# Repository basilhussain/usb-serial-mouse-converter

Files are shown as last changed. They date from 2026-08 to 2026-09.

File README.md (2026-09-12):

# USB-to-Serial Mouse Converter

This is an adapter to convert a USB mouse to work with an RS-232 serial interface. Gives the capability to use a modern USB optical mouse with vintage PC computer hardware, where original serial ball mice are frequently scarce, unreliable, or just unpleasant to use.

Designed to be mounted with a bracket internally in a regular PC expansion card chassis slot.

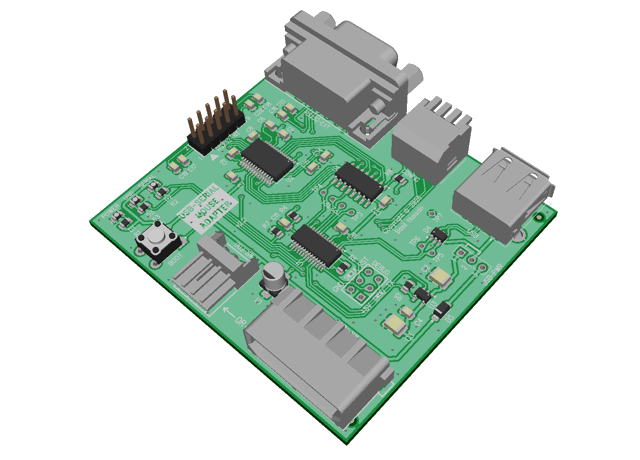
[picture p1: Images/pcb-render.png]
Rendered image of PCB

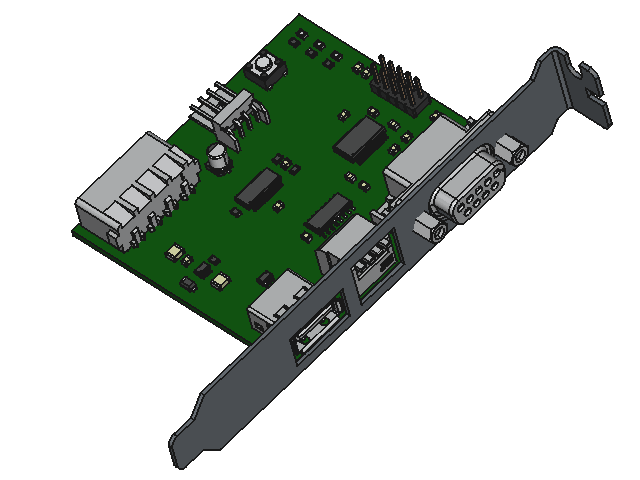
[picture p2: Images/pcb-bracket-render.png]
Rendered image of PCB with mounting bracket


## Features

* Emulates four different serial mouse types:
  * Microsoft 2-button
  * Mouse Systems 3-button
  * Logitech 3-button
  * Microsoft 3-button wheel
* Supports virtually any USB HID pointing device – mouse, trackball, touchpad – including scroll wheel, wireless, combo, and hi-DPI devices.
* Connects to host system's RS-232 serial port via either:
  * External female DE-9 connector
  * Internal male 10-pin header
* Powered by regular PC power supply connector, either larger Molex HDD-type or smaller Berg FDD-type.
* Custom bracket design for mounting in standard PC expansion card chassis slot.
* Configuration adjustable via externally-accessible DIP switches.
* USB port short-circuit and over-current protected (500 mA capable).
* Supports optional Plug-and-Play ID for auto-detection by capable operating systems (e.g. Win9x) and drivers.
* Supports subset of proprietary Logitech serial probe/identification commands for auto-detection by Logitech drivers.
* Firmware upgradable over USB.

## Installation & Setup

1. Screw the adapter board's bracket into a free chassis expansion slot.
2. Plug a spare power supply cable into **either** the larger Molex HDD-type **or** smaller Berg FDD-type power connectors. **Do not use both power connectors.**
3. Connect **either** external **or** internal serial cables, as described below.
4. Configure DIP switches according to desired usage (see *Configuration* section).

> [!NOTE]
> The adapter board does not plug into the motherboard expansion bus, so if you have a free chassis slot that doesn't have a corresponding motherboard connection, use that to avoid taking up space that could otherwise be used for a card!

### External Serial Cable

**You will require a male-to-female 9-pin DE-9 RS-232 serial cable.**

1. Connect one end of the cable to the 9-pin port on the adapter.
2. Connect the other end of the cable to a free 9-pin serial port on the host machine. Effectively, you're looping the serial cable from the machine back to itself.
3. Set port selection DIP switch to 'External' (see *Configuration* section below).

### Internal Serial Cable

**You will require a 10-pin ribbon cable with 5x2 dual-row 2.54mm (0.1") pitch female IDC connectors.**

The internal serial connection is designed to connect to an internal pin header on the motherboard or a serial expansion card of the host machine.

> [!IMPORTANT]
> The internal 10-pin header uses the 'Intel' pin-out; it is not compatible with the other common 'AT'/'Everex' pin-out.

1. Connect one end of the cable to the adapter's pin header labelled `RS232-INT`. Note the arrow indicating pin 1, which should align with the red stripe on the cable.
2. Connect the other end of the cable to the host machine's internal RS232 port header. Again, ensure the red stripe is aligned to pin 1. Be aware that pin 1 markings on motherboards and expansion cards may vary, so if not immediately apparent, inspect closely.
3. Set port selection DIP switch to 'Internal' (see *Configuration* section below).

If in doubt about host machine's serial header location, orientation, or exact pin-out, refer to your motherboard or serial expansion card's documentation.

> [!NOTE]
> You may need to alter jumpers, DIP switches, or BIOS settings to enable and configure (port address, IRQ, etc.) an internal serial port header.

### Configuration

Serial mouse emulation type, Plug-and-Play ID, and external/internal serial port selection are configured via DIP switches.

> [!IMPORTANT]
> If you change any of the switches (except the port selection switch) while the system is running, you will need to either unload and re-load the mouse driver or restart the system for changes to take effect.

Numeric column headings in the tables below correspond to the labels on the DIP switch, and the off/on values in each row are what each individual switch should be set to.

#### Serial Mouse Type

Selects what type of serial mouse to emulate.

| Serial Mouse Type | 1 | 2 |
| --- |:---:|:---:|
| Microsoft 2-button | OFF | OFF |
| Mouse Systems 3-button | ON  | OFF |
| Logitech 3-button | OFF | ON  |
| Microsoft 3-button Wheel | ON  | ON  |

Logitech emulation includes support for Logitech-proprietary probing/identification commands sent to the serial mouse, but not any others such as baud rate, protocol, or report rate switching. Logitech command support is disabled when PnP is enabled.

Microsoft Wheel support depends on both driver and application support; otherwise, wheel will be limited to acting as middle button.

#### Plug and Play ID

Whether to emit Plug and Play ('PnP') data when the host driver or operating system resets/probes the mouse (by toggling the serial RTS line), so that the mouse can be automatically identified.

| PnP ID | 3 |
| --- |:---:|
| Disabled | OFF |
| Enabled  | ON  |

Enable this switch when using Windows 9x (or any other O/S that supports PnP). Disable when using DOS or Windows 3.x.

This switch has no effect in Microsoft 2-button and Mouse Systems mode (i.e. always acts as if disabled) – these mice pre-date PnP, so there is no identifier for them.

#### RS-232 Port Select

Selects between the internal or external RS-232 serial ports.

| RS-232 Port | 4 |
| --- |:---:|
| Internal | OFF |
| External | ON  |

Unlike the other switches, **this switch is 'live'** – i.e. takes effect immediately.

### Other Operational Notes

There are three on-board LEDs:

* 🟢 **Power** (green) – Should illuminate whenever the board is receiving 5V power from the Molex connector.
* 🔴 **USB status and activity** (red) – Will illuminate when a USB mouse is connected and has been successfully enumerated. Will flash when USB activity is occurring. Activity should be fairly constant regardless of movement or clicking due to the regular USB polling traffic.
* 🔴 **Serial status and activity** (red) – Will illuminate when the serial RTS signal has been asserted; i.e. when a driver has enabled and probed the serial mouse. Will flash when serial data is being sent. Activity will generally only be indicated when the mouse is moved, clicked, or scrolled.

**Connecting USB devices through a USB hub is not supported.** The USB device must be directly connected to the adapter.

The USB port is over-current and short-circuit protected. Maximum allowed current draw is approximately 500mA. Should the current limit be exceeded, the USB power will be shut off and the USB status LED will go out. To recover from this state, the board must be power-cycled.

The 3-way jumper labelled `USB-PWR` is only used for facilitating firmware upgrades via the USB port and should not normally need adjustment. **It must always be in the 1-2 position during normal operation.** The other position (2-3) allows for powering the board via the USB port during firmware updates.

## Hardware

For schematic, PCB layout, and Bill of Materials (BOM), see the `Hardware` sub-folder.

Gerber files for PCB manufacturing and 3D STEP file for sheet-metal mounting bracket can all be found in the 'Releases' section of the GitHub repository.

## Firmware

For firmware source files, firmware update procedure, and build procedure, see the `Firmware` sub-folder.

You can find the latest compiled firmware in the 'Releases' section of the GitHub repository.

## Motivation

There are many existing open-source projects to adapt USB mice to a serial interface, so why yet another?

A lot of other projects are somewhat limited, flawed, or buggy. Many don't properly support all varieties of USB mice, have limited serial mouse emulation, or make mistakes or omissions in their handling of certain features. Most also do unnecessary work due to lack of understanding of the USB specification.

I decided to create this project to address many of these shortcomings.

Below I'll discuss a little on some of the more notable things I discovered while researching existing solutions.

### Simplified Boot vs. Native Report Modes

One particular flaw common to all projects found based on the Raspberry Pi Pico microcontrollers is caused by their use of the ubiquitous [Tinyusb](https://github.com/hathach/tinyusb/) library.

Out of the box, the Tinyusb library only works with USB HID mice that support 'Boot' mode. In the HID standard, Boot mode is a simplified, limited-capability mode intended for BIOSes and other system bootloaders, so that they don't have to implement the entire, complex HID specification. In Boot mode mouse reports follow a standardised, fixed report format that is limited to low resolution (8-bit) axis values and only 3 buttons.

However, some mice either do not support Boot mode at all, or when told to use Boot mode wrongly continue to report their native higher-resolution (e.g. 12- or 16-bit) data in an incompatible format.

Boot mode also does not cater to more complex devices (e.g. a combo device such as keyboard with integrated trackpad) that use Report IDs to differentiate between reports sent for each sub-function.

All this leads to Tinyusb-based projects often having limited USB device compatibility; they tend not to work with 'fancier' devices like high-DPI mice or combo devices.

### "Hey, Not So Fast!"

Another common flaw comes from an apparent lack of detailed understanding of the USB specification, particularly when combined with use of a library that abstracts away some of the details of USB devices.

When a USB device is first connected, the enumeration process involves the device sending some 'descriptor' data to the host. This descriptor data describes what class of device it is, its capabilities, etc. One part of this data that is supplied by devices such as mice and keyboards is the `bInterval` field of an Endpoint descriptor. This tells the host system how often (in milliseconds) the USB device would like to be polled for data. For example, a mouse might give a `bInterval` of 10ms; that is, it can provide updates 100 times per second.

However, when it comes to serial mice, their update rate is limited by the rate at which they can spit data across the slow serial connection. Typical serial baud rate is only 1200 baud, which if you do the math works out to (depending on protocol) between 24 to 44 possible updates per second.

This disparity between update rates causes many projects to implement some kind of aggregation scheme, where they will collect multiple more-frequent USB reports and sum the pointer movement between serial updates.

But what if I told you that is wholly unnecessary? You see, that `bInterval` value mentioned earlier is a *minimum* interval time; it's the *fastest* rate at which the USB device should be polled. There's actually nothing stopping you from polling a USB mouse at a *slower* rate! So you can simply match your USB polling rate to the fastest rate at which you can send serial updates, and the mouse just does all the aggregation for you!

### Identity Problems

Some projects do not properly implement the process of the emulated serial mouse identifying itself to the host system when the host toggles the RTS line of the serial port.

In one, when working in basic 2-button Microsoft mode, the ident value incorrectly claims to be a 3-button mouse. Another identifies as a 3-button mouse, but in update reports never actually sends the 4th protocol byte containing the state of the middle button. Lastly, another tries to identify with additional Plug-and-Play ID data, but unfortunately the data it supplies is malformed.

## Resources

Here are some links to helpful technical resources concerning USB, HID, serial mouse protocols, and more, as well as a selection of other open-source projects.

### References

* [*Universal Serial Bus Specification, Revision 2.0*](https://www.usb.org/document-library/usb-20-specification) - USB Implementers Forum
* [*USB Device Class Definition for Human Interface Devices (HID), Version 1.1*](https://www.usb.org/document-library/device-class-definition-hid-111) - USB Implementers Forum
* [*HID Usage Tables for Universal Serial Bus (USB), Version 1.7*](https://usb.org/document-library/hid-usage-tables-17) - USB Implementers Forum
* [*USB in a NutShell*](https://www.beyondlogic.org/usbnutshell/usb1.shtml) - Beyond Logic
* [*Plug and Play External COM Device Specification, Rev. 1.00*](https://ftpmirror.your.org/pub/misc/ftp.microsoft.com/developr/drg/Plug-and-Play/Pnpspecs/) - Microsoft Corporation
* [*Hardware Design Guide for Microsoft Windows 95*](https://archive.org/details/bitsavers_microsoftwignGuideforWindows951994_24657772) - Microsoft Press
* [*LogiMouse C7 Technical Reference Manual*](https://archive.org/details/bitsavers_logitechLormwareRev3.0Jan86_1143953) - Logitech Inc.
* *3D Mouse & Head Tracker Technical Reference Manual* - Logitech Inc.
* [*CyberMan 3D SWIFT Supplement, Version 1.0*](https://archive.org/details/bitsavers_logitechcyFTSupplementVer1.0upd199401_3268361) - Logitech Inc.
* [*Differences between the Logitech Mouseman and C7/C9 Serial Mouse?*](https://www.scosales.com/ta/kb/104043.html) - SCO Unix Support Knowledge Base
* *M-1 Mouse Technical Reference Manual* - Mouse Systems Corporation
* [*M-2 Optical Mouse Technical Reference Manual*](https://archive.org/details/bitsavers_mouseSysteicalMouseTechnicalReferenceJan1984_519574) - Mouse Systems Corporation
* [*Optical Mouse Technical Reference Manual, Models M2 and M3*](https://archive.org/details/bitsavers_mouseSystetemsOpticalMouseTechnicalReferenceModels_351372) - Mouse Systems Corporation
* *HT82M13, HT82M33A, HT6513 Datasheets* - Holtek
* *EM83701, EM84520 Datasheets* - EMC
* [*The RS-232 Solution*](https://archive.org/details/The_RS-232_Solution_by_Joe_Campbell) - Joe Campbell, Sybex Computer Books
* [*Design Notes: Interface Circuits for TIA/EIA-232-F (SLLA037A)*](https://www.ti.com/lit/an/slla037a/slla037a.pdf) - Texas Instruments
* [*Serial Mouse Info, Release 05*](https://web.archive.org/web/19991116104658/http://www.softnco.demon.co.uk/SerialMouse.txt) - Chris Softley
* [*PC Mouse Information*](https://www.epanorama.net/documents/pc/mouse.html) - Tomi Engdahl
* [*Protocol Documentation*](https://github.com/davidebreso/ctmouse/blob/main/doc/protocol.txt) - CuteMouse Driver

Apologies that links to all items cannot be provided, as some were acquired from non-linkable or non-public resources, or from sources that have been forgotten. 😅

### Other Projects

* https://github.com/Yftul/usb-mouse-2-isa
* https://github.com/Aviancer/amouse/
* https://github.com/LimeProgramming/USB-serial-mouse-adapter
* https://github.com/polpo/picogus/
* https://github.com/rasteri/HIDman
* https://github.com/mborjesson/USB-Mouse-to-Serial
* https://github.com/6502addict/usb-to-serial-mouse
* https://github.com/Lameguy64/LameMouseConverter
* https://github.com/matze79/PS2-Adapter
* https://github.com/mniemela/PS2toSerial
* https://github.com/Quwy/PS2-Serial-Mouse
* https://github.com/trol73/avr-mouse-ps2-to-serial
* https://github.com/necroware/ps2-serial-mouse-adapter/
* https://github.com/danbrakeley/PS2toCDi

## Licence

Copyright © 2026 Basil Hussain.

Firmware is licenced under the [GNU General Public License 3.0](https://www.gnu.org/licenses/gpl-3.0.html); see accompanying LICENCE.txt for details. Uses [Nanoprintf](https://github.com/charlesnicholson/nanoprintf) by Charles Nicholson, licenced under the terms of [Unlicense](http://unlicense.org).

Hardware schematic and PCB design is licenced under the [Creative Commons Attribution-NonCommercial-ShareAlike 4.0 International](https://creativecommons.org/licenses/by-nc-sa/4.0/) licence.

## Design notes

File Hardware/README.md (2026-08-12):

This folder contains the design files for PCB schematic and layout, as well as 3D model for mounting bracket.

Gerber files for PCB manufacturing and 3D STEP file for sheet-metal mounting bracket can all be found in the 'Releases' section of the GitHub repository.

Schematic and PCB layout were created with [DipTrace](https://diptrace.com) version 5.x.

Mounting bracket 3D model was created in [FreeCAD](https://www.freecad.org) version 1.x.

## Bill of Materials

| Reference Designator | Type | Value | Package | Specification | Manufacturer | Manufacturer Part Number | Alternative Parts (Mfr. & P/N) | Quantity | LCSC Part Number |
| --- | --- | ----- | --- | --- | --- | --- | --- | --- | --- |
| C1 | Electrolytic Capacitor | 10µF  | | ≥16V, ±20%, ≥2000h @ ≥85°C, 4mm diameter, ≤6mm height | (Any) | | | 1 | C249565 |
| C2, C3 | Ceramic Capacitor | 10µF  | 1210 | ≥50V, ±10%, X5R/X7S/X7R | (Any) | | | 2 | C2918502 |
| C4, C5, C6, C7, C8, C9, C10, C11, C12 | Ceramic Capacitor | 100nF | 0805 | ≥25V, ±10%, X7R | (Any) | | | 9 | C1711 |
| C13, C14, C15, C16 | Ceramic Capacitor | 4.7nF | 0805 | ≥25V, ±10%, X7R | (Any) | | | 4 | C1744 |
| D1 | LED | | 0805 | Yellow-Green, ~572 nm, 25-75 mcd @ 5mA IF | (Any) | | | 1 | C965816 |
| D2, D3 | LED | | 0805 | Red, ~620 nm, 25-75 mcd @ 5mA IF | (Any) | | | 2 | C965812 |
| D4 | TVS Diode | | SOT23-6 | | ST Microelectronics | USBLC6-2SC6 | | 1 | C5180249 |
| D5 | Schottky Diode | | SOD-123FL | ≥20V, ≥200mA, ≥400mW | (Any) | 1N5819W | 1N5817W; BAT43W; BAT42W | 1 | C963381 |
| J1 ‡ | Connector | | | Berg/FDD, 4-pin, 2.5mm pitch, horizontal, through-hole | TE | 171826-4 | XKB X2511WR-04A; CJT A2544WR-4P; Hongxing HX25025-4WA | 1 | C590635 |
| J2 ‡ | Connector | | | Molex/HDD, 4-pin, 5.08mm pitch, horizontal, through-hole | TE | 641737-1 | XFCN M5082RK-04P | 1 | C492552 |
| J3 | Connector | | | DE-9, female, horizontal | TE | 2311765-1 | XUNPU D-SUB-DR-9PCM-CB | 1 | C19077337 |
| J4 | Pin Header | | | 2.54mm pitch, 2x5, vertical | (Any) | | | 1 | C42385496 |
| J5 | Connector | | | USB type-A, female, horizontal, through-hole | TE | 292303-6 | SHOU HAN AF 90 WJDG | 1 | C456018 |
| J6 | Pin Header | | | 2.54mm pitch, 1x5, vertical | (Any) | | | 1 | |
| J7 | Pin Header | | | 2.54mm pitch, 1x3, vertical | (Any) | | | 1 | |
| R1, R2, R3 | Resistor | 1kΩ | 0805 | ±5%, 125mW, 150V | (Any) | | | 3 | C25623 |
| R4, R5, R6, R7, R8 | Resistor | 4.7kΩ | 0805 | ±5%, 125mW, 150V | (Any) | | | 5 | C26022 |
| S1 | DIP Switch | | | 4 switches, SPST, piano key, 2.54mm pitch, 7.62mm width | (Any) | | | 1 | C5299494 |
| S2 | Tactile Switch | | | 4-pin, 6x6mm, through-hole, vertical, round button | (Any) | | | 1 | C393938 |
| U1 | Microcontroller | | SOP28 | | WCH | CH32X035G8R6 | | 1 | C49118551 |
| U2 | RS-232 Transceiver | | SOP28 | 4 drivers, 5 receivers | MaxLinear | SP213EEA-L/TR | Gatemode GM213EBA; Texas Instruments TRS213EIDBR; Maxim Integrated MAX213EEAI; Analog Devices ADM213EARSZ | 1 | C415725 |
| U3 | Power Distribution Switch | | SOT23-5 | 0.5A nominal current output, output discharge, active-high EN input, active-low FLT output | Texas Instruments | TPS2051CDBVR | Texas Instruments TPS2051CDBVT; Richtek RT9742QGJ5; Silergy SY6288AAAC; Shenzhen JingYang (JY) TP6062FX; Fitipower FP6861C-C1AS5 | 1 | C129581 |
| U4 | Analog Multiplexer | | SOIC16 | 4-channel, 2:1 | Texas Instruments | SN74CBT3257CD | HXY SN74CBT3257CDR; Tech Public SN74CBTLV3257DR-TP; ON Semi 74FST3257DR2G; Runic RS2233YS16; SG Micro SGM330A-YS/TR; Tech Public TPCH440G; WCH CH440G | 1 | C51912456 |
| | Jumper | | | 2.54mm pitch, 1x2, open-top, black | (Any) | | | 1 | C5305 |
| † | IDC Ribbon Cable | | | 2x 10-pin 2.54mm pitch 2x5 IDC connectors, 1.27mm pitch ribbon cable, 28AWG | (Any) | | | 1 | C7496754 |
| † | RS-232 Cable | | | DE-9 9-pin M-to-F | (Any) | | | 1 | |

† – Optional, depending on how you intend to make the RS-232 serial connection to the host system.

‡ – May be optional; if you don't intend to use one type of power connector, it can be omitted. 

## PCB Specification

* 1.6 mm thickness
* 2 layers
* 1 oz / 35 µm copper

## Mounting Bracket Specification

* Laser-cut sheet metal
* Stainless steel
* 1 mm thickness
* One 90° bend operation

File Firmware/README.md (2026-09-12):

This folder contains the source code files for the firmware that runs on the embedded microcontroller.

## Overview

The firmware runs on an embedded RISC-V microcontroller, a [WCH CH32X035](https://www.wch-ic.com/products/CH32X035.html), which serves as a USB host and handles enumeration of the HID USB pointing device and reception of its regular reports. These reports are translated into the appropriate serial protocol format and sent via RS-232 serial UART to the host system. When the host system probes the serial port (by toggling the RTS line), the firmware also responds with identifying information.

The firmware code is written entirely in C.

## Updating the Firmware

The firmware of the on-board microcontroller can be upgraded via the USB port. You can find the latest firmware in the 'Releases' section of the GitHub repository.

### Pre-requisites

* Type-A male to Type-A male USB cable.
* A Windows computer with a USB port and [WCH ISP Tool software](https://www.wch-ic.com/downloads/WCHISPTool_Setup_exe.html) downloaded and installed.

### Procedure

1. Unplug cables from **all** connectors on the board – USB, serial, and power.
2. Set the jumper labelled `USB-PWR` to position 2-3.
3. Connect one end of A-to-A USB cable to the computer being used to run the update software.
4. Start the WCH ISP Tool software.
5. While holding down the `BOOT` button, plug other end of the USB cable into the board's USB connector.
6. After a couple of seconds, release the `BOOT` button.
7. The microcontroller should automatically be detected. The *Chip Option* panel should show series `CH32X03x`, model `CH32X035G8R6`, and port `USB`.
8. In the *Download File* panel, click the folder icon in the first row of the table (*Object File1*) and select the `.hex` firmware file. Ensure the checkbox in the right-hand column is ticked, and that all other rows are blank.
9. Click the *Download* button at the bottom of the window.
10. Wait for the firmware download process to occur. It should go through three stages: erasing, programming, and verifying, which should all report as completing successfully.
11. Unplug the USB cable.
12. Return `USB-PWR` jumper to position 1-2.
13. Reconnect USB mouse, serial, and power cables as they were before.

## Building

A Windows build environment with installations of the [xPack GCC RISC-V compiler](https://xpack-dev-tools.github.io/riscv-none-elf-gcc-xpack/) and [xPack Windows Build Tools](https://xpack-dev-tools.github.io/windows-build-tools-xpack/) is assumed. It may be possible to build on other platforms with the appropriate RISC-V cross-compiler (riscv-none-elf-gcc) and tools (make, objcopy, etc.) but this has not been provided for or tested.

### Compiling

1. Run the `setenv-prompt.bat` batch file. This will open a command prompt with the appropriate paths set for xPack tools.
2. From the command prompt, run `make` to compile.
3. Firmware files in both ELF (`.elf`) and Intel Hex format (`.hex`) will be placed in a `bin` sub-folder.

> [!NOTE]
> You may need to edit the `setenv-prompt.bat` batch file and alter the exact paths due to package release or version number differences.

To remove all build artifacts (binaries, object files, etc.) in the `bin` and `obj` folders, run `make clean`.

### Programming

The easiest procedure for programming the firmware on a newly-built board is to follow the procedure for USB firmware updates above.

Alternatively, if you have a copy of WCH's fork of OpenOCD installed (e.g. from MounRiver Studio) and in path, plus a WCH LinkE programming adapter connected to the `DEBUG` header, you can run `make flash` to program.

### Debugging

The firmware can optionally be configured to output various informational and diagnostic messages to a dedicated UART pin, labelled `TX`, present on the board's `DEBUG` header.

When compiling, give an argument of `DEBUG_VERBOSITY=<value>` to the `make` command, where 'value' is one of the following: `ERROR`, `WARN`, `INFO`, `TRACE`. The least verbose is `ERROR` and `TRACE` the most. To turn off all debug messages entirely, specify the value `OFF`.

The debug UART operates at a baud rate of 256 kbit, with 8 data bits, 1 stop bit, no parity.

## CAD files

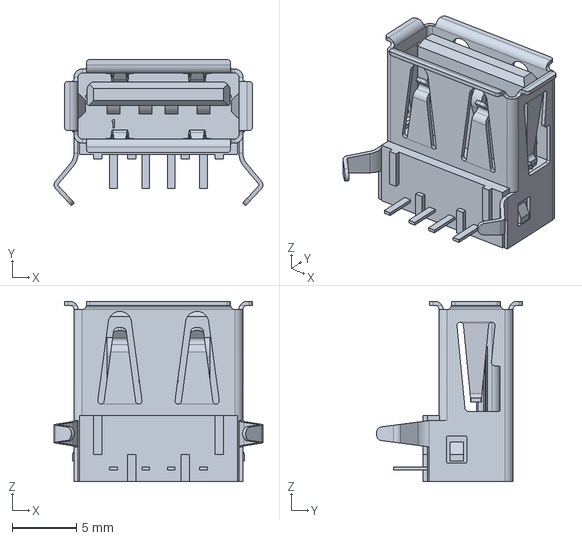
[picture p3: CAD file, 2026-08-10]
Hardware/3D Models/TE c-292303-6-f-3d.stp
16.2 x 11.4 x 14.0 mm

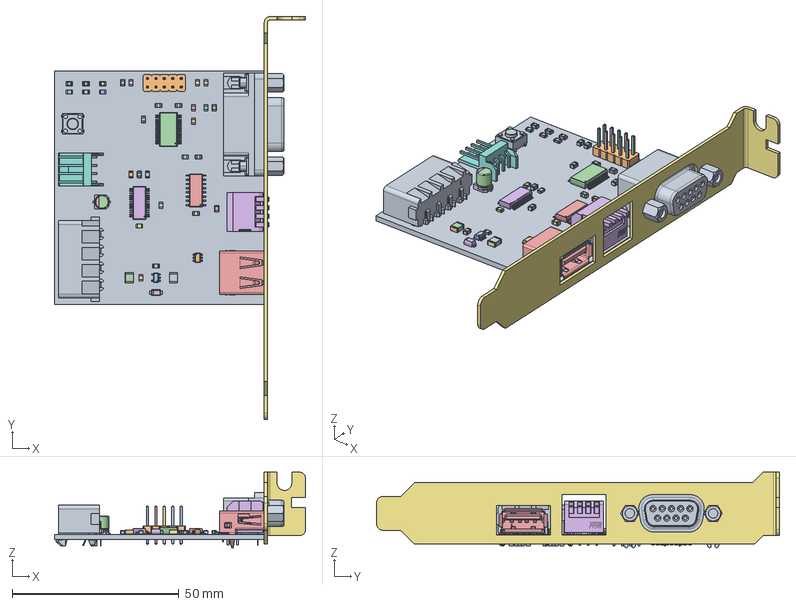
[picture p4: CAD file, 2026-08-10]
Hardware/Card Bracket v2.2 - Rev 4.FCStd
75.4 x 121.0 x 22.7 mm
Board_USB_to_Serial_Mouse_Converter_v2.2
CAP_POLARIZED1
CAP_POLARIZED002
CAP_POLARIZED003
CAP_POLARIZED004
CAP_POLARIZED005
CAP_NONPOLARIZED
CAP_NONPOLARIZED001
CAP_NONPOLARIZED002
CAP_NONPOLARIZED004
CAP_NONPOLARIZED005
CAP_NONPOLARIZED006
CAP_NONPOLARIZED008
CAP_NONPOLARIZED009
CAP_NONPOLARIZED010
CAP_NONPOLARIZED012
CAP_NONPOLARIZED013
CAP_NONPOLARIZED014
CAP_NONPOLARIZED016
CAP_NONPOLARIZED017
CAP_NONPOLARIZED018
CAP_NONPOLARIZED020
CAP_NONPOLARIZED021
CAP_NONPOLARIZED022
CAP_NONPOLARIZED024
CAP_NONPOLARIZED025
CAP_NONPOLARIZED026
CAP_NONPOLARIZED028
CAP_NONPOLARIZED029
CAP_NONPOLARIZED030
CAP_NONPOLARIZED032
CAP_NONPOLARIZED033
CAP_NONPOLARIZED034
CAP_NONPOLARIZED036
CAP_NONPOLARIZED037
CAP_NONPOLARIZED038
CAP_NONPOLARIZED040
CAP_NONPOLARIZED041
CAP_NONPOLARIZED042
CAP_NONPOLARIZED044
CAP_NONPOLARIZED045
CAP_NONPOLARIZED046
CAP_NONPOLARIZED048
CAP_NONPOLARIZED049
CAP_NONPOLARIZED050
CAP_NONPOLARIZED052
CAP_NONPOLARIZED053
CAP_NONPOLARIZED054
CAP_NONPOLARIZED056
CAP_NONPOLARIZED057
CAP_NONPOLARIZED058
CAP_NONPOLARIZED060
CAP_NONPOLARIZED061
CAP_NONPOLARIZED062
CAP_NONPOLARIZED064
CAP_NONPOLARIZED065
CAP_NONPOLARIZED066
CAP_NONPOLARIZED068
CAP_NONPOLARIZED069
CAP_NONPOLARIZED070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

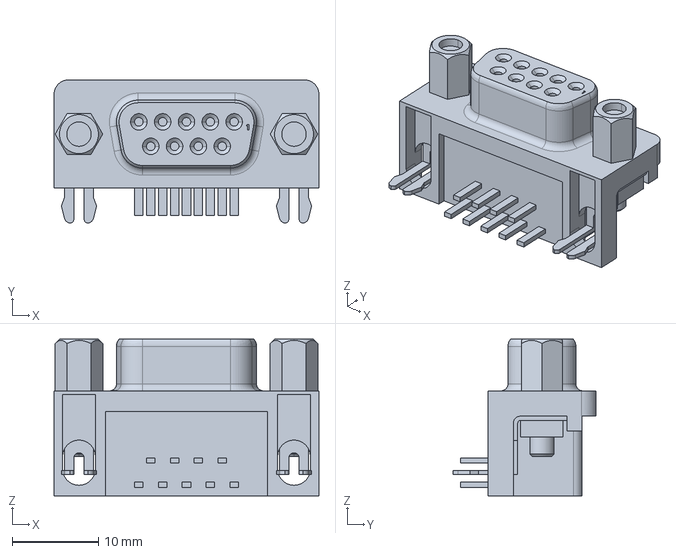
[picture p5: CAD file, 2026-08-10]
Hardware/3D Models/TE c-2311765-1-b-3d.stp
30.8 x 16.6 x 18.2 mm

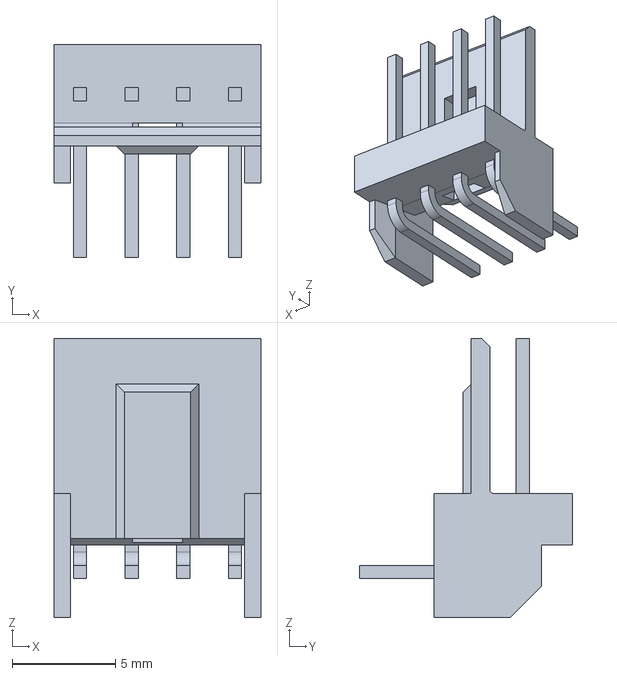
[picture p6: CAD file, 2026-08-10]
Hardware/3D Models/TE c-171826-4-y3-3d.stp
10.0 x 10.3 x 13.5 mm

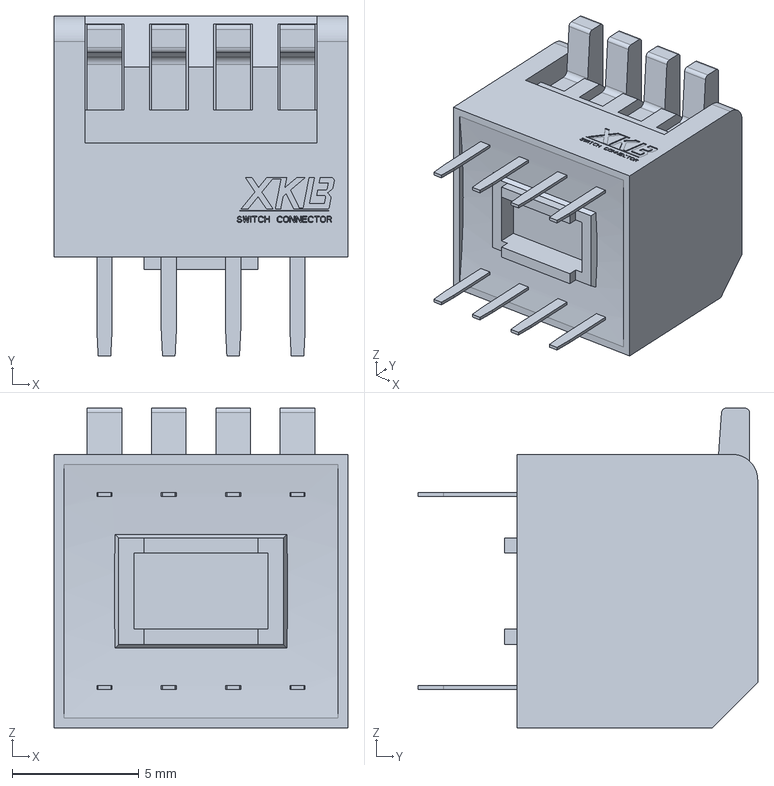
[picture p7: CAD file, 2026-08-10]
Hardware/3D Models/XKB DPL-04RP.stp
11.6 x 13.4 x 12.6 mm

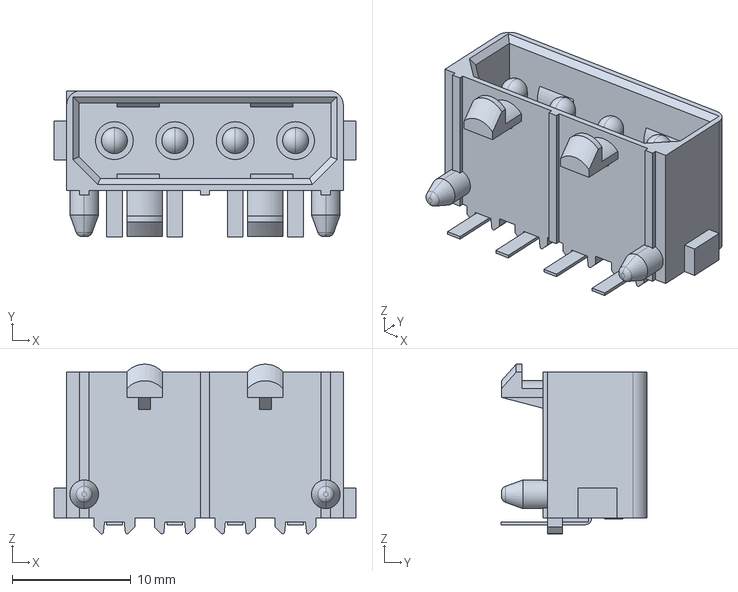
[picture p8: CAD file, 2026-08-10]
Hardware/3D Models/TE c-0641737-01-g-3d.stp
25.4 x 12.3 x 14.3 mm

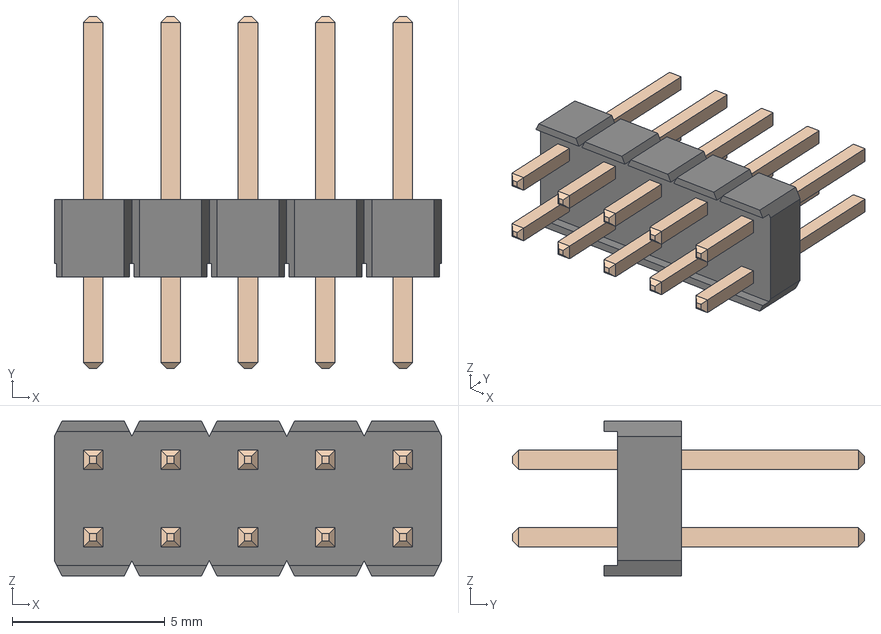
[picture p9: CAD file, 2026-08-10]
Hardware/3D Models/Wurth 61301021121 (rev1).stp
12.7 x 11.5 x 5.08 mm
6130xx21121_PIN x 10

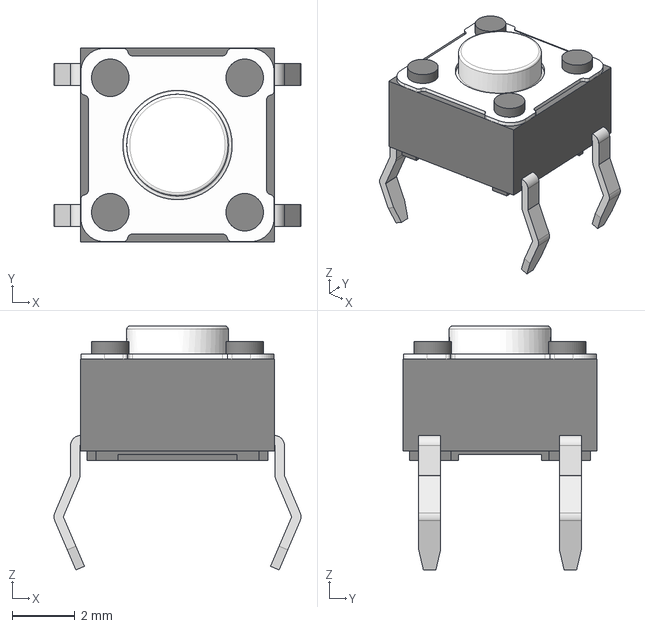
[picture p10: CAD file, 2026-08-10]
Hardware/3D Models/Wurth 430186043716 (rev1).stp
7.90 x 6.20 x 7.80 mm

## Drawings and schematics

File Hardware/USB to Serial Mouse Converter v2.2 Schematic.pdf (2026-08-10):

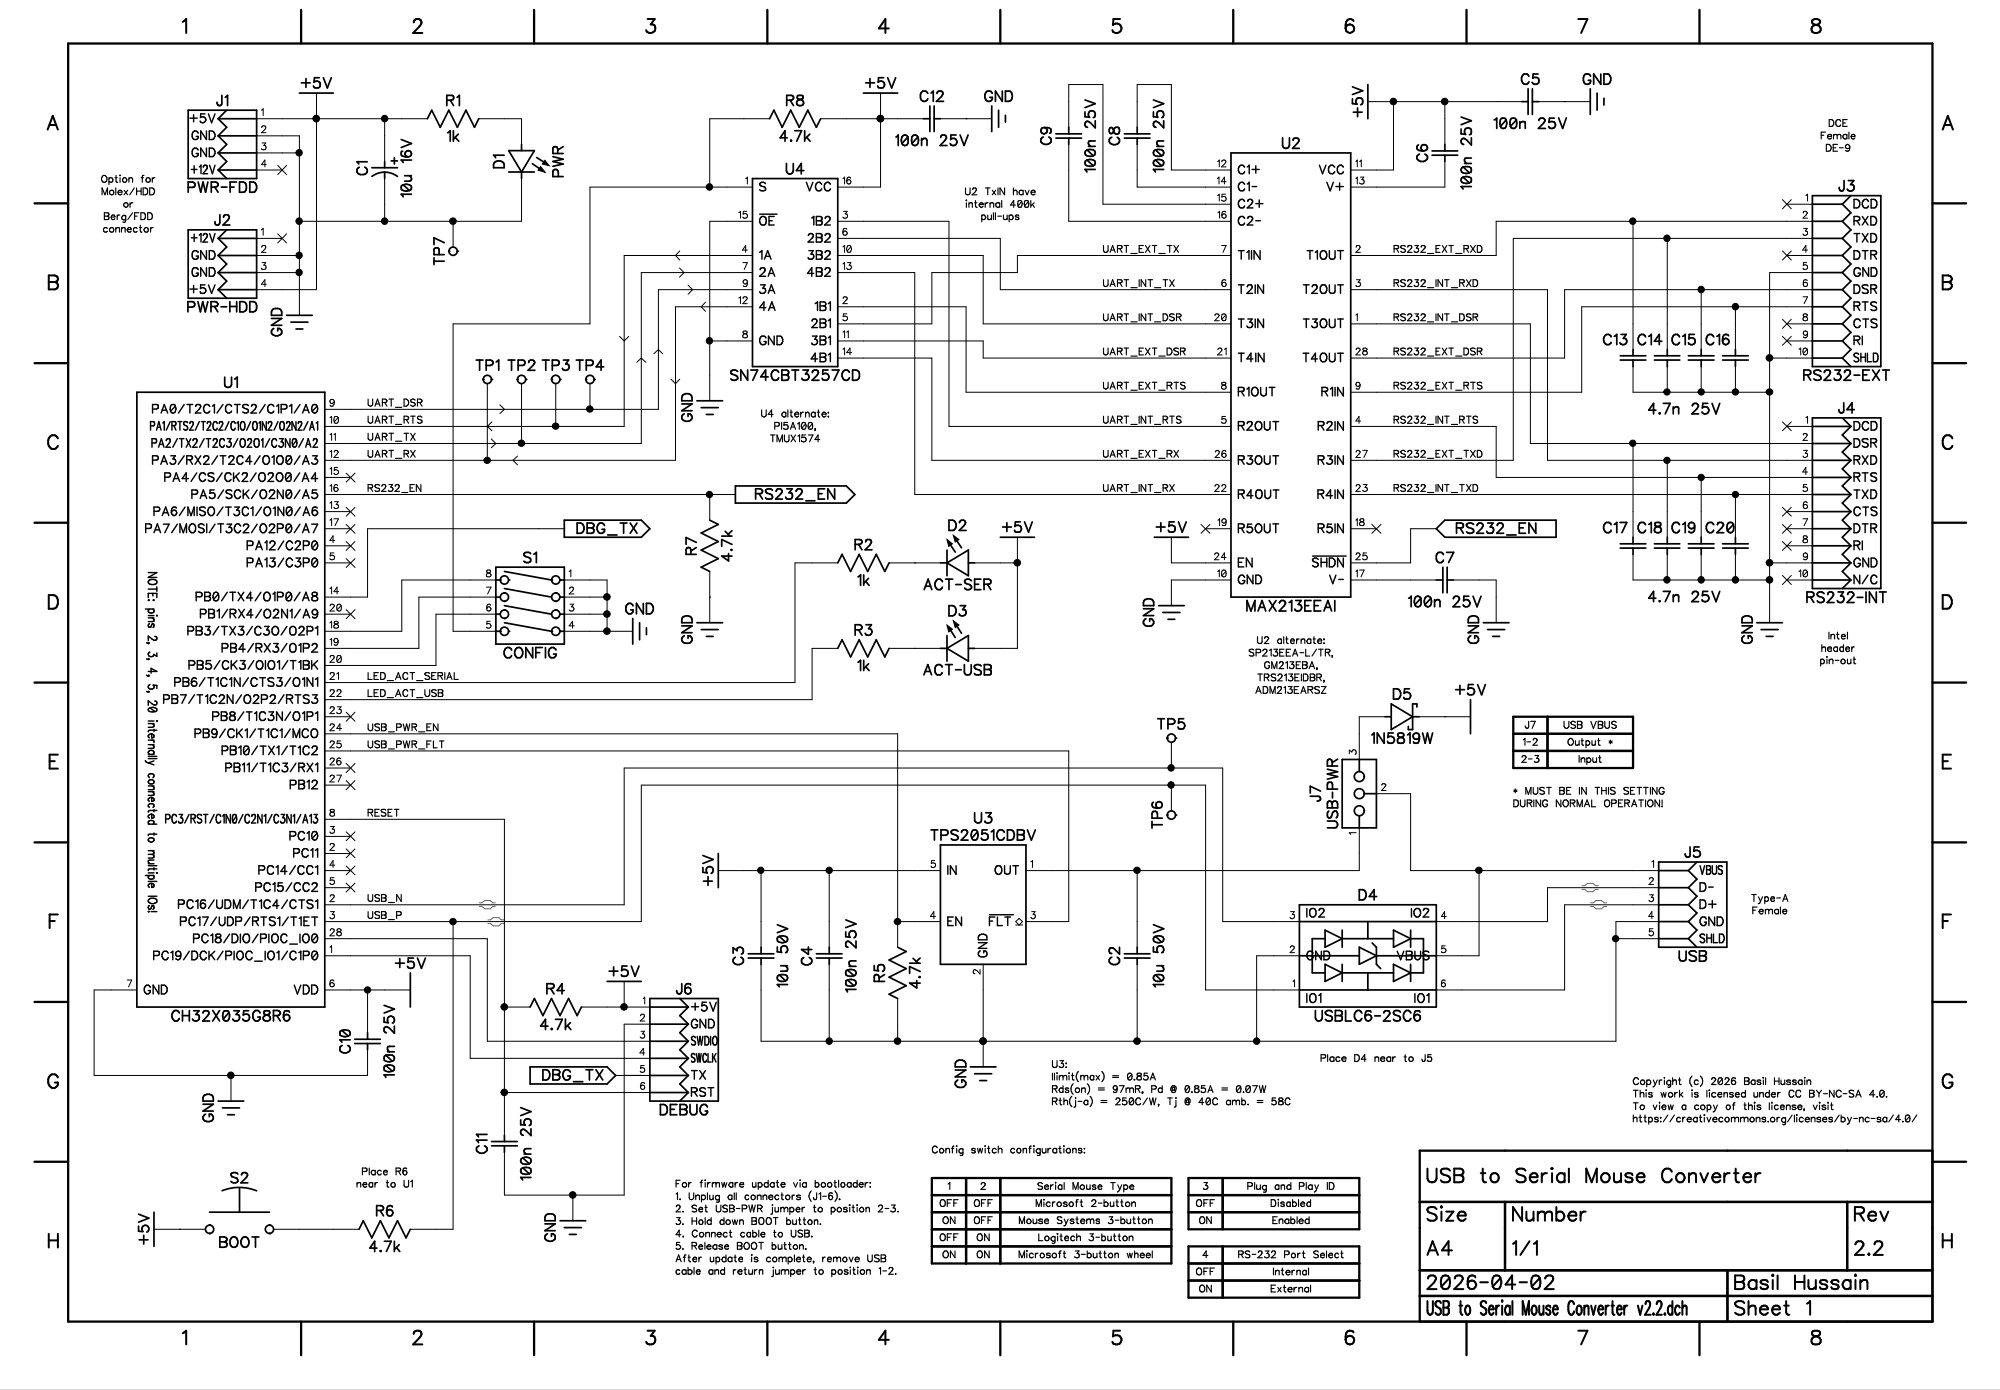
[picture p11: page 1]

NOTE: pins 2, 3, 4, 5, 20 internally connected to multiple IOs!

* MUST BE IN THIS SETTING
DURING NORMAL OPERATION!

Copyright (c) 2026 Basil Hussain
This work is licensed under CC BY-NC-SA 4.0.
To view a copy of this license, visit
https://creativecommons.org/licenses/by-nc-sa/4.0/

For firmware update via bootloader:
1. Unplug all connectors (J1-6).
2. Set USB-PWR jumper to position 2-3.
3. Hold down BOOT button.
4. Connect cable to USB.
5. Release BOOT button.
After update is complete, remove USB
cable and return jumper to position 1-2.

Plug and Play ID
Disabled
Enabled

USB to Serial Mouse Converter

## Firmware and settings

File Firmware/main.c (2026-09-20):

/*******************************************************************************
 *
 * USB to Serial Mouse Converter firmware
 * Copyright (c) 2026 Basil Hussain
 * 
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
 * SPDX-License-Identifier: GPL-3.0-or-later
 *
 ******************************************************************************/

#include <stddef.h>
#include <stdint.h>
#include <stdbool.h>
#include <stdlib.h>
#include <stdio.h>
#include <string.h>
#include "ch32x035.h"
#include "interrupt.h"
#include "debug.h"
#include "tstamp.h"
#include "event.h"
#include "uart_mouse.h"
#include "usb.h"
#include "hid.h"
#if defined(PRINTF_SDI)
#include "sdi.h"
#elif defined(PRINTF_UART)
#include "uart_debug.h"
#endif

/*
COMMON PIN-OUT FOR ALL CH32X035:
PA0 - UART_DSR, output push-pull (active-low)
PA1 - UART_RTS, input with internal pull-up (active-low)
PA2 - UART_TX, output push-pull
PA3 - UART_RX, input with internal pull-up
PA5 - RS232_EN, output push-pull
PB0 - DEBUG_UART_TX, output push-pull
PB3 - CONFIG_0, input with internal pull-up (active-low)
PB4 - CONFIG_1, input with internal pull-up (active-low)
PB5 - CONFIG_2, input with internal pull-up (active-low)
PB6 - LED_ACT_SERIAL, output push-pull (active-low)
PB7 - LED_ACT_USB, output push-pull (active-low)
PB9 - USB_PWR_EN, output push-pull (active-high)
PB10 - USB_PWR_FLT, input with internal pull-up (active-low)
PC16 - USBDM, input with internal pull-down (req'd for USB host)
PC17 - USBDP, input with internal pull-down (req'd for USB host)
PC18 - SWDIO, input floating
PC19 - SWCLK, input floating

PIN-OUT FOR CH32X035C8T6:
PA21 - NRST, input with internal pull-up (active-low)

PIN-OUT FOR CH32X035G8R6:
PC3 - NRST, input with internal pull-up (active-low)
*/

// Serial UART debug output baud rate in bits-per-second.
#define UART_DEBUG_BAUD_RATE 256000

// The serial mouse communications baud rate, in bits-per-second.
#define SERIAL_MOUSE_BAUD_RATE 1200

// Switches 1 & 2 are serial mouse type/mode.
// Switch 3 is plug-and-play ident mode on/off.
// Switch 4 is RS-232 port selection (internal/external), but directly switches
// multiplexer and isn't connected to GPIO.
#define CONFIG_SWITCH_MODE_MASK 0b0011
#define CONFIG_SWITCH_PNP_MASK 0b0100

// How long the total period (i.e. off plus on time) of activity LED blinking
// shall be. A fixed 50% duty cycle is used, so off time is equal to on time.
#define LED_ACT_BLINK_PERIOD_MS 200

// These values match bit pattern for mode DIP switch settings.
typedef enum {
	SERIAL_MOUSE_MODE_MICROSOFT       = 0, // 2 buttons
	SERIAL_MOUSE_MODE_MOUSE_SYSTEMS   = 1, // 3 buttons
	SERIAL_MOUSE_MODE_LOGITECH        = 2, // MouseMan, a.k.a. M+, 3 buttons
	SERIAL_MOUSE_MODE_MICROSOFT_WHEEL = 3  // Intellimouse, 3 buttons + wheel
} serial_mouse_mode_enum_t;

// Maximum possible size in bytes of each kind of serial mouse packet.
typedef enum {
	SERIAL_MOUSE_PACKET_SIZE_MICROSOFT       = 3,
	SERIAL_MOUSE_PACKET_SIZE_MOUSE_SYSTEMS   = 5,
	SERIAL_MOUSE_PACKET_SIZE_LOGITECH        = 4,
	SERIAL_MOUSE_PACKET_SIZE_MICROSOFT_WHEEL = 4
} serial_mouse_packet_size_enum_t;

typedef struct {
	const hid_input_t *hid_input;
	size_t bit_offset;
	union {
		bool bin;
		int32_t num;
	} value;
	union {
		bool bin;
		int32_t num;
	} prev_value;
} usb_hid_mouse_input_t;

typedef struct {
	hid_report_composition_t composition;
	usb_hid_mouse_input_t button_1;
	usb_hid_mouse_input_t button_2;
	usb_hid_mouse_input_t button_3;
	usb_hid_mouse_input_t x_axis;
	usb_hid_mouse_input_t y_axis;
	usb_hid_mouse_input_t wheel;
} usb_hid_mouse_inputs_t;

/******************************************************************************/

// USB HID report descriptor for standard mouse 'boot' protocol reports, as
// defined in HID v1.11 specification Appendix B.2.
static const uint8_t hid_boot_mouse_std_report_descr[50] = {
	0x05, 0x01, // Usage Page (Generic Desktop Ctrls)
	0x09, 0x02, // Usage (Mouse)
	0xA1, 0x01, // Collection (Application)
	0x09, 0x01, //   Usage (Pointer)
	0xA1, 0x00, //   Collection (Physical)
	0x95, 0x03, //     Report Count (3)
	0x75, 0x01, //     Report Size (1)
	0x05, 0x09, //     Usage Page (Button)
	0x19, 0x01, //     Usage Minimum (0x01)
	0x29, 0x03, //     Usage Maximum (0x03)
	0x15, 0x00, //     Logical Minimum (0)
	0x25, 0x01, //     Logical Maximum (1)
	0x81, 0x02, //     Input (Data,Var,Abs,No Wrap,Linear,Preferred State,No Null Position)
	0x95, 0x01, //     Report Count (1)
	0x75, 0x05, //     Report Size (5)
	0x81, 0x03, //     Input (Const,Var,Abs,No Wrap,Linear,Preferred State,No Null Position)
	0x75, 0x08, //     Report Size (8)
	0x95, 0x02, //     Report Count (2)
	0x05, 0x01, //     Usage Page (Generic Desktop Ctrls)
	0x09, 0x30, //     Usage (X)
	0x09, 0x31, //     Usage (Y)
	0x15, 0x81, //     Logical Minimum (-127)
	0x25, 0x7F, //     Logical Maximum (127)
	0x81, 0x06, //     Input (Data,Var,Rel,No Wrap,Linear,Preferred State,No Null Position)
	0xC0,       //   End Collection
	0xC0        // End Collection
};

static usb_context_t usb_ctx;
static uint8_t usb_mouse_intf_num = 0, usb_mouse_endp_addr = 0, usb_mouse_endp_interval_ms = 0;
static usb_hid_mouse_inputs_t usb_mouse_inputs;
static timestamp_interval_call_handle_t mouse_interval_call_handle;
static serial_mouse_mode_enum_t serial_mouse_mode = SERIAL_MOUSE_MODE_MICROSOFT;
static uart_mouse_format_enum_t serial_mouse_data_format = UART_MOUSE_FORMAT_7N1;
static bool serial_mouse_pnp = false;
static uint8_t serial_mouse_interval_ms = 0;
static uint32_t led_act_serial_counter = 0, led_act_usb_counter = 0;
static timestamp_interval_call_handle_t led_act_serial_blink_tick_handle, led_act_usb_blink_tick_handle;

/******************************************************************************/

static void clock_init(void) {
	// Ensure HSI is on, and wait for it to be ready, just in case. (But if it
	// isn't on, how're we even running this code? CH32X035 only has HSI.)
	RCC->CTLR |= RCC_HSION;
	while(!(RCC->CTLR & RCC_HSIRDY));
	
	// Configure for no MCO and HCLK equal to the default SYSCLK divided by 6.
	RCC->CFGR0 = RCC_MCO_NOCLOCK | RCC_HPRE_DIV6;

    // Configure flash for 2 wait states.
    FLASH->ACTLR = FLASH_ACTLR_LATENCY_2;

    // Set HCLK to be equal to SYSCLK undivided.
    RCC->CFGR0 = (RCC->CFGR0 & ~RCC_HPRE) | RCC_HPRE_DIV1;
}

static void gpio_init_disable_port_unused(GPIO_TypeDef *port) {
	// Set all GPIOs in the given port to be analog inputs (output buffer is
	// disconnected, input Schmitt triggers disabled, pull-up/down resistors are
	// disabled). This ensures that any that are not externally exposed in the
	// chip package, share a pin with another GPIO, or are exposed but later
	// unused, are 'disabled'.
	port->CFGLR = 0;
	port->CFGHR = 0;
	port->CFGXR = 0;
}

static void gpio_init_lock_port_cfg(GPIO_TypeDef *port) {
	// Perform the special locking sequence on the LCKK key bit (write 1,
	// write 0, write 1, read 0, read 1; last is optional) for all pins on the
	// given port.
	port->LCKR = GPIO_LCKK | (UINT32_MAX & ~GPIO_LCKK);
	port->LCKR = (UINT32_MAX & ~GPIO_LCKK);
	port->LCKR = GPIO_LCKK | (UINT32_MAX & ~GPIO_LCKK);
	port->LCKR;
}

static void gpio_init(void) {
	// Enable peripheral clocks for GPIO ports A, B, and C.
	RCC->APB2PCENR |= RCC_IOPAEN | RCC_IOPBEN | RCC_IOPCEN;

	gpio_init_disable_port_unused(GPIOA);
	gpio_init_disable_port_unused(GPIOB);
	gpio_init_disable_port_unused(GPIOC);
	
	// Configure GPIO port A.
	// Pull-up on PA1 (UART_RTS) & PA3 (UART_RX), default PA0 (UART_DSR) to
	// unasserted (high). Default PA5 (RS232_EN) low.
	GPIOA->BSHR = GPIO_BSHR_BS0 | GPIO_BSHR_BS1 | GPIO_BSHR_BS3;
	GPIOA->BCR = GPIO_BCR_BR5;
	GPIOA->CFGLR = (
		GPIO_CFGLR_MODE0_OUTPUT_2M | GPIO_CFGLR_CNF0_OUTPUT_PUSH_PULL |
		GPIO_CFGLR_MODE1_INPUT | GPIO_CFGLR_CNF1_INPUT_PULL |
		GPIO_CFGLR_MODE2_OUTPUT_2M | GPIO_CFGLR_CNF2_OUTPUT_MUX_PUSH_PULL |
		GPIO_CFGLR_MODE3_INPUT | GPIO_CFGLR_CNF3_INPUT_PULL |
		GPIO_CFGLR_MODE5_OUTPUT_2M | GPIO_CFGLR_CNF5_OUTPUT_PUSH_PULL
	);	
#ifdef CH32X035C8T6
	GPIOA->BSXR = GPIO_BSXR_BS21; // Pull-up on PA21 NRST.
	GPIOA->CFGXR = (
		GPIO_CFGXR_MODE21_INPUT | GPIO_CFGXR_CNF21_INPUT_PULL
	);
#endif

	// Configure GPIO port B.
	// Pull-ups on PB3/4/5 (CONFIG_n) and PB10 (USB_PWR_FLT), and default both
	// PB6/7 (ACT LEDs) to off (high), and PB9 (USB_PWR_EN) low.
	GPIOB->BSHR = GPIO_BSHR_BS3 | GPIO_BSHR_BS4 | GPIO_BSHR_BS5 | GPIO_BSHR_BS6 | GPIO_BSHR_BS7 | GPIO_BSHR_BS10;
	GPIOB->BCR = GPIO_BCR_BR9;
	GPIOB->CFGLR = (
		GPIO_CFGLR_MODE0_OUTPUT_2M | GPIO_CFGLR_CNF0_OUTPUT_MUX_PUSH_PULL |
		GPIO_CFGLR_MODE3_INPUT | GPIO_CFGLR_CNF3_INPUT_PULL |
		GPIO_CFGLR_MODE4_INPUT | GPIO_CFGLR_CNF4_INPUT_PULL |
		GPIO_CFGLR_MODE5_INPUT | GPIO_CFGLR_CNF5_INPUT_PULL |
		GPIO_CFGLR_MODE6_OUTPUT_2M | GPIO_CFGLR_CNF6_OUTPUT_PUSH_PULL |
		GPIO_CFGLR_MODE7_OUTPUT_2M | GPIO_CFGLR_CNF7_OUTPUT_PUSH_PULL
	);
	GPIOB->CFGHR = (
		GPIO_CFGHR_MODE9_OUTPUT_2M | GPIO_CFGHR_CNF9_OUTPUT_PUSH_PULL |
		GPIO_CFGHR_MODE10_INPUT | GPIO_CFGHR_CNF10_INPUT_PULL
	);

	// Configure GPIO port C.
#ifdef CH32X035G8R6
	GPIOC->BSHR = GPIO_BSHR_BS3; // Pull-up on PC3 NRST.
	GPIOC->CFGLR = (
		GPIO_CFGLR_MODE3_INPUT | GPIO_CFGLR_CNF3_INPUT_PULL
	);
#endif
	GPIOC->BCR = GPIO_BCR_BR16 | GPIO_BCR_BR17; // Pull-down on PC16 & PC17.
	GPIOC->CFGXR = (
		GPIO_CFGXR_MODE16_INPUT | GPIO_CFGXR_CNF16_INPUT_PULL |
		GPIO_CFGXR_MODE17_INPUT | GPIO_CFGXR_CNF17_INPUT_PULL |
		GPIO_CFGXR_MODE18_INPUT | GPIO_CFGXR_CNF18_INPUT_FLOAT |
		GPIO_CFGXR_MODE19_INPUT | GPIO_CFGXR_CNF19_INPUT_FLOAT
	);
	
	gpio_init_lock_port_cfg(GPIOA);
	gpio_init_lock_port_cfg(GPIOB);
	gpio_init_lock_port_cfg(GPIOC);

	// Configure for both falling-edge and rising-edge interrupts on PA1
	// (UART_RTS) with EXTI channel 1 to catch when RTS is asserted (active-low)
	// and de-asserted. But don't enable the interrupt right now.
	AFIO->EXTICR[0] = (AFIO->EXTICR[0] & ~AFIO_EXTICR1_EXTI1) | AFIO_EXTICR1_EXTI1_PA;
	EXTI->FTENR |= EXTI_FTENR_TR1;
	EXTI->RTENR |= EXTI_RTENR_TR1;
	EXTI->INTENR &= ~EXTI_INTENR_MR1;
	
	// Configure for falling-edge interrupt on PB10 (USB_PWR_FLT) with EXTI
	// channel 10 to catch fault condition on the USB power switch (active-low).
	// But don't enable the interrupt right now.
	AFIO->EXTICR[0] = (AFIO->EXTICR[0] & ~AFIO_EXTICR1_EXTI10) | AFIO_EXTICR1_EXTI10_PB;
	EXTI->FTENR |= EXTI_FTENR_TR10;
	EXTI->INTENR &= ~EXTI_INTENR_MR10;

	// Enable the EXTI interrupts in the PFIC.
	interrupt_enable(EXTI7_0_IRQn);
	interrupt_enable(EXTI15_8_IRQn);
}

static void led_act_serial_enable(const bool enabled) {
	// Enabled or disable the blink counter tick callback as appropriate, and
	// also reset the counter to zero.
	timestamp_interval_call_set_enabled(led_act_serial_blink_tick_handle, enabled);
	led_act_serial_counter = 0;
	
	// Turn on/off the LED immediately.
	if(enabled) {
		GPIOB->BCR = GPIO_BCR_BR6; // Turn on active-low LED.
	} else {
		GPIOB->BSHR = GPIO_BSHR_BS6; // Turn off active-low LED.
	}
}

static void led_act_usb_enable(const bool enabled) {
	// Enabled or disable the blink counter tick callback as appropriate, and
	// also reset the counter to zero.
	timestamp_interval_call_set_enabled(led_act_usb_blink_tick_handle, enabled);
	led_act_usb_counter = 0;
	
	// Turn on/off the LED immediately.
	if(enabled) {
		GPIOB->BCR = GPIO_BCR_BR7; // Turn on active-low LED.
	} else {
		GPIOB->BSHR = GPIO_BSHR_BS7; // Turn off active-low LED.
	}
}

static void led_act_serial_blink(void) {
	if(led_act_serial_counter == 0) led_act_serial_counter = LED_ACT_BLINK_PERIOD_MS;
}

static void led_act_usb_blink(void) {
	if(led_act_usb_counter == 0) led_act_usb_counter = LED_ACT_BLINK_PERIOD_MS;
}

static void led_act_serial_blink_tick(void) {
	if(led_act_serial_counter > 0) led_act_serial_counter--;
	
	if(led_act_serial_counter > (LED_ACT_BLINK_PERIOD_MS / 2)) {
		GPIOB->BSHR = GPIO_BSHR_BS6; // Turn off active-low LED.
	} else {
		GPIOB->BCR = GPIO_BCR_BR6; // Turn on active-low LED.
	}
}

static void led_act_usb_blink_tick(void) {
	if(led_act_usb_counter > 0) led_act_usb_counter--;
	
	if(led_act_usb_counter > (LED_ACT_BLINK_PERIOD_MS / 2)) {
		GPIOB->BSHR = GPIO_BSHR_BS7; // Turn off active-low LED.
	} else {
		GPIOB->BCR = GPIO_BCR_BR7; // Turn on active-low LED.
	}
}

/*
static void debug_tick(void) {
	timestamp_t now;
	timestamp_now(&now);
	debug_info("ticks = %lu", now.ticks);
}
*/

static const char * config_serial_mode_name(const serial_mouse_mode_enum_t mode) {
	static const char * mode_names[] = {
		[SERIAL_MOUSE_MODE_MICROSOFT] = "Microsoft",
		[SERIAL_MOUSE_MODE_MOUSE_SYSTEMS] = "Mouse Systems",
		[SERIAL_MOUSE_MODE_LOGITECH] = "Logitech",
		[SERIAL_MOUSE_MODE_MICROSOFT_WHEEL] = "Microsoft Wheel"
	};
	
	return (mode < (sizeof(mode_names) / sizeof(mode_names[0])) ? mode_names[mode] : "[unknown]");
}

static const char * config_serial_format_name(const uart_mouse_format_enum_t format) {
	static const char * format_names[] = {
		[UART_MOUSE_FORMAT_7N1] = "7N1",
		[UART_MOUSE_FORMAT_8N1] = "8N1"
	};
	
	return (format < (sizeof(format_names) / sizeof(format_names[0])) ? format_names[format] : "[unknown]");
}

static void config_switch_read(serial_mouse_mode_enum_t * const serial_mode, uart_mouse_format_enum_t * const serial_format, bool * const pnp) {
	// Read the switch values. Switches are active-low (off = high, on = low),
	// so invert the values.
	const uint32_t switch_vals = (~GPIOB->INDR & (GPIO_INDR_IDR3 | GPIO_INDR_IDR4 | GPIO_INDR_IDR5)) >> __builtin_ctz(GPIO_INDR_IDR3);
	
	debug_trace("GPIOB = 0x%lX, switch_vals = 0x%lX", GPIOB->INDR, switch_vals);
	
	// Switches 1 & 2 are serial mouse type/mode. Mode enum values correspond
	// directly to switch value bits.
	if(serial_mode != NULL && serial_format != NULL) {
		*serial_mode = (serial_mouse_mode_enum_t)(switch_vals & CONFIG_SWITCH_MODE_MASK);
		
		// Serial format differs depending on mouse mode; select accordingly.
		switch(*serial_mode) {
			case SERIAL_MOUSE_MODE_MICROSOFT:
			case SERIAL_MOUSE_MODE_LOGITECH:
			case SERIAL_MOUSE_MODE_MICROSOFT_WHEEL:
				*serial_format = UART_MOUSE_FORMAT_7N1;
				break;
			case SERIAL_MOUSE_MODE_MOUSE_SYSTEMS:
				*serial_format = UART_MOUSE_FORMAT_8N1;
				break;
		}
		
		debug_info("serial_mode = %s (%lu), serial_format = %s (%lu)", config_serial_mode_name(*serial_mode), *serial_mode, config_serial_format_name(*serial_format), *serial_format);
	}
	
	// Switch 3 is whether PnP data should be included in ident.
	if(pnp != NULL) {
		*pnp = (bool)(switch_vals & CONFIG_SWITCH_PNP_MASK);
		
		debug_info("pnp = %u", *pnp);
	}
}

static inline int32_t serial_mouse_clamp_value(const int32_t value, const int32_t min, const int32_t max) {
	if(value > max) return max;
	if(value < min) return min;
	return value;
}
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
int main(void) {
	event_t event = { .type = EVENT_TYPE_NONE };

	clock_init();
	gpio_init();
#if defined(PRINTF_SDI)
	sdi_init(HCLK);
#elif defined(PRINTF_UART)
	uart_debug_init(HCLK, UART_DEBUG_BAUD_RATE);
#endif
	timestamp_init(HCLK);
	event_fifo_init();
	uart_mouse_init(HCLK, SERIAL_MOUSE_BAUD_RATE, UART_MOUSE_FORMAT_7N1);
	usb_host_init();

#if defined(PRINTF_SDI)
	timestamp_interval_call_add(sdi_process_queue, 2, true);
#endif
	/*timestamp_interval_call_add(debug_tick, 1000, true);*/
	led_act_serial_blink_tick_handle = timestamp_interval_call_add(led_act_serial_blink_tick, 1, false);
	led_act_usb_blink_tick_handle = timestamp_interval_call_add(led_act_usb_blink_tick, 1, false);
	
	timestamp_delay_ms(2000);

	debug_always("----------------------------------------");
	debug_always("USB TO SERIAL MOUSE CONVERTER");
	debug_always("----------------------------------------");
	debug_always("copyright (c) 2026 Basil Hussain");
	debug_always("built " __DATE__ " at " __TIME__);

	config_switch_read(&serial_mouse_mode, &serial_mouse_data_format, &serial_mouse_pnp);
	
	// Set serial mouse UART format according to config.
	uart_mouse_set_format(serial_mouse_data_format);

	// Calculate how long it will take the serial mouse in current mode to
	// transmit a packet, and set up the periodic callback for that period
	// length for polling the USB mouse for reports. Don't enable the callback
	// just yet, though (will be done later). Put simply, only poll the USB
	// mouse as quickly as we can transmit a full serial data packet.
	serial_mouse_interval_ms = serial_mouse_transmit_time_ms(SERIAL_MOUSE_BAUD_RATE, serial_mouse_data_format, serial_mouse_packet_size(serial_mouse_mode));
	mouse_interval_call_handle = timestamp_interval_call_add(usb_mouse_interval_callback, serial_mouse_interval_ms, false);

	usb_power_enable(true);

	// Do an initial check to see if we already have a USB device attached. If
	// so, manually push a connect event to the queue.
	if(usb_have_device_attached()) {
		event_fifo_push((event_t){
			.type = EVENT_TYPE_USB_DEV_CONNECT,
			.param.word = 0
		});
	}

	while(true) {
		// Attempt to pull the next event from the queue.
		if(event_fifo_pop(&event)) {
			debug_trace("event, type = 0x%lX, param = 0x%lX", event.type, event.param.word);
			
			switch(event.type) {
				case EVENT_TYPE_USB_DEV_CONNECT:
					event_usb_device_connected();
					break;
				case EVENT_TYPE_USB_DEV_DISCONNECT:
					event_usb_device_disconnected();
					break;
				case EVENT_TYPE_USB_PWR_FAULT:
					event_usb_power_fault();
					break;
				case EVENT_TYPE_USB_MOUSE_INTERRUPT:
					event_usb_mouse_interrupt();
					break;
				case EVENT_TYPE_SERIAL_MOUSE_ENABLE:
					event_serial_mouse_enable();
					break;
				case EVENT_TYPE_SERIAL_MOUSE_DISABLE:
					event_serial_mouse_disable();
					break;
				case EVENT_TYPE_NONE:
					// Do nothing.
					break;
				default:
					debug_error("unhandled event, type = 0x%lX, param = 0x%lX", event.type, event.param.word);
					break;
			}
		}
		
		// Later Logitech drivers don't use asterisk commands to probe the mouse
		// to identify it, but instead use Plug-n-Play. So don't bother to
		// process any received serial commands if PnP mode is enabled.
		if(serial_mouse_mode == SERIAL_MOUSE_MODE_LOGITECH && !serial_mouse_pnp) {
			serial_mouse_process_logitech_command();
		}
	}
}

ISR(EXTI7_0_IRQHandler) {
	// Did we get an EXTI interrupt for channel 1 (i.e. PA1)? If so, this means
	// we have UART_RTS toggled. If signal remains low after the interrupt, then
	// RTS was asserted; if high, RTS was de-asserted.
	if(EXTI->INTFR & EXTI_INTF_INTF1) {
		if(GPIOA->INDR & GPIO_INDR_IDR1) {
			event_fifo_push((event_t){
				.type = EVENT_TYPE_SERIAL_MOUSE_DISABLE,
				.param.word = 0
			});
		} else {
			event_fifo_push((event_t){
				.type = EVENT_TYPE_SERIAL_MOUSE_ENABLE,
				.param.word = 0
			});
		}

		// Clear the interrupt flag (by just writing '1').
		EXTI->INTFR = EXTI_INTF_INTF1;
	}
}

ISR(EXTI15_8_IRQHandler) {
	// Did we get an EXTI interrupt for channel 10 (i.e. PB10)? If so, this
	// means we have USB_PWR_FLT asserted. If signal is still low after the
	// falling edge triggered interrupt, raise an event for the error condition.
	if(EXTI->INTFR & EXTI_INTF_INTF10) {
		if(!(GPIOB->INDR & GPIO_INDR_IDR10)) {
			event_fifo_push((event_t){
				.type = EVENT_TYPE_USB_PWR_FAULT,
				.param.word = 0
			});
		}

		// Clear the interrupt flag (by just writing '1').
		EXTI->INTFR = EXTI_INTF_INTF10;
	}
}

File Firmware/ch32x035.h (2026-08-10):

#ifndef __CH32X035_H
#define __CH32X035_H

#include <stdint.h>

#ifdef __cplusplus
extern "C" {
#endif

#define HSI_VALUE              ((uint32_t)48000000) /* Frequency, in Hz, of the High-Speed Internal RC oscillator */

/* Interrupt Number Definition, according to the selected device */
typedef enum IRQn
{
	/******  RISC-V Processor Exceptions Numbers *******************************************************/
	NonMaskableInt_IRQn = 2,   /* 2 Non Maskable Interrupt                             */
	EXC_IRQn = 3,              /* 3 Exception Interrupt                                */
	Ecall_M_Mode_IRQn = 5,     /* 5 Ecall M Mode Interrupt                             */
	Ecall_U_Mode_IRQn = 8,     /* 8 Ecall U Mode Interrupt                             */
	Break_Point_IRQn = 9,      /* 9 Break Point Interrupt                              */
	SysTick_IRQn = 12,         /* 12 System timer Interrupt                            */
	Software_IRQn = 14,        /* 14 software Interrupt                                */

	/******  RISC-V specific Interrupt Numbers *********************************************************/
	WWDG_IRQn = 16,            /* Window WatchDog Interrupt                            */
	PVD_IRQn = 17,             /* PVD through EXTI Line detection Interrupt            */
	FLASH_IRQn = 18,           /* FLASH global Interrupt                               */
	EXTI7_0_IRQn = 20,         /* External Line[7:0] Interrupts                        */
	AWU_IRQn = 21,             /* AWU global Interrupt                                 */
	DMA1_Channel1_IRQn = 22,   /* DMA1 Channel 1 global Interrupt                      */
	DMA1_Channel2_IRQn = 23,   /* DMA1 Channel 2 global Interrupt                      */
	DMA1_Channel3_IRQn = 24,   /* DMA1 Channel 3 global Interrupt                      */
	DMA1_Channel4_IRQn = 25,   /* DMA1 Channel 4 global Interrupt                      */
	DMA1_Channel5_IRQn = 26,   /* DMA1 Channel 5 global Interrupt                      */
	DMA1_Channel6_IRQn = 27,   /* DMA1 Channel 6 global Interrupt                      */
	DMA1_Channel7_IRQn = 28,   /* DMA1 Channel 7 global Interrupt                      */
	ADC1_IRQn = 29,            /* ADC1 global Interrupt                                */
	I2C1_EV_IRQn = 30,         /* I2C1 Event Interrupt                                 */
	I2C1_ER_IRQn = 31,         /* I2C1 Error Interrupt                                 */
	USART1_IRQn = 32,          /* USART1 global Interrupt                              */
	SPI1_IRQn = 33,            /* SPI1 global Interrupt                                */
	TIM1_BRK_IRQn = 34,        /* TIM1 Break Interrupt                                 */
	TIM1_UP_IRQn = 35,         /* TIM1 Update Interrupt                                */
	TIM1_TRG_COM_IRQn = 36,    /* TIM1 Trigger and Commutation Interrupt               */
	TIM1_CC_IRQn = 37,         /* TIM1 Capture Compare Interrupt                       */
	TIM2_UP_IRQn = 38,         /* TIM2 Update Interrupt                                */
	USART2_IRQn = 39,          /* USART2 global Interrupt                              */
	EXTI15_8_IRQn = 40,        /* External Line[15:8] Interrupts                       */
	EXTI25_16_IRQn = 41,       /* External Line[25:16] Interrupts                      */
	USART3_IRQn = 42,          /* USART3 global Interrupt                              */
	USART4_IRQn = 43,          /* USART4 global Interrupt                              */
	DMA1_Channel8_IRQn = 44,   /* DMA1 Channel 8 global Interrupt                      */
	USBFS_IRQn = 45,           /* USBFS Host/Device global Interrupt                   */
	USBFSWakeUp_IRQn = 46,     /* USBFS Host/Device WakeUp Interrupt                   */
	PIOC_IRQn = 47,            /* PIOC global Interrupt                                */
	OPA_IRQn = 48,             /* OPA global Interrupt                                 */
	USBPD_IRQn = 49,           /* USBPD global Interrupt                               */
	USBPDWakeUp_IRQn = 50,     /* USBPD WakeUp Interrupt                               */
	TIM2_CC_IRQn = 51,         /* TIM2 Capture Compare Interrupt                       */
	TIM2_TRG_COM_IRQn = 52,    /* TIM2 Trigger and Commutation Interrupt               */
	TIM2_BRK_IRQn = 53,        /* TIM2 Break Interrupt                                 */
	TIM3_IRQn = 54,            /* TIM3 global Interrupt                                */
} IRQn_Type;

#define HardFault_IRQn    EXC_IRQn
#define SysTicK_IRQn      SysTick_IRQn

/* IO definitions */
#ifdef __cplusplus
  #define     __I     volatile                /* defines 'read only' permissions */
#else
  #define     __I     volatile const          /* defines 'read only' permissions */
#endif
#define       __O     volatile                /* defines 'write only' permissions */
#define       __IO    volatile                /* defines 'read / write' permissions */

/* memory mapped structure for Program Fast Interrupt Controller (PFIC) */
typedef struct{
	__I  uint32_t ISR[8];
	__I  uint32_t IPR[8];
	__IO uint32_t ITHRESDR;
	__IO uint32_t RESERVED;
	__IO uint32_t CFGR;
	__I  uint32_t GISR;
	__IO uint8_t VTFIDR[4];
	uint8_t RESERVED0[12];
	__IO uint32_t VTFADDR[4];
	uint8_t RESERVED1[0x90];
	__O  uint32_t IENR[8];
	uint8_t RESERVED2[0x60];
	__O  uint32_t IRER[8];
	uint8_t RESERVED3[0x60];
	__O  uint32_t IPSR[8];
	uint8_t RESERVED4[0x60];
	__O  uint32_t IPRR[8];
	uint8_t RESERVED5[0x60];
	__IO uint32_t IACTR[8];
	uint8_t RESERVED6[0xE0];
	__IO uint8_t IPRIOR[256];
	uint8_t RESERVED7[0x810];
	__IO uint32_t SCTLR;
} PFIC_Type;

/* memory mapped structure for SysTick */
typedef struct
{
	__IO uint32_t CTLR;
	__IO uint32_t SR;
	__IO uint64_t CNT;
	__IO uint64_t CMP;
} SysTick_Type;

/* Debug Module Data Registers */
typedef struct
{
    __IO uint32_t DATA0;
    __IO uint32_t DATA1;
} DBGDAT_Type;

/* Analog to Digital Converter */
typedef struct
{
	__IO uint32_t STATR;
	__IO uint32_t CTLR1;
	__IO uint32_t CTLR2;
	__IO uint32_t SAMPTR1;
	__IO uint32_t SAMPTR2;
	__IO uint32_t IOFR1;
	__IO uint32_t IOFR2;
	__IO uint32_t IOFR3;
	__IO uint32_t IOFR4;
	__IO uint32_t WDHTR;
	__IO uint32_t WDLTR;
	__IO uint32_t RSQR1;
	__IO uint32_t RSQR2;
	__IO uint32_t RSQR3;
	__IO uint32_t ISQR;
	__IO uint32_t IDATAR1;
	__IO uint32_t IDATAR2;
	__IO uint32_t IDATAR3;
	__IO uint32_t IDATAR4;
	__IO uint32_t RDATAR;
	__IO uint32_t CTLR3;
	__IO uint32_t WDTR1;
	__IO uint32_t WDTR2;
	__IO uint32_t WDTR3;
} ADC_TypeDef;

/* DMA Channel Controller */
typedef struct
{
	__IO uint32_t CFGR;
	__IO uint32_t CNTR;
	__IO uint32_t PADDR;
	__IO uint32_t MADDR;
} DMA_Channel_TypeDef;

/* DMA Controller */
typedef struct
{
	__IO uint32_t INTFR;
	__IO uint32_t INTFCR;
} DMA_TypeDef;

/* External Interrupt/Event Controller */
typedef struct
{
	__IO uint32_t INTENR;
	__IO uint32_t EVENR;
	__IO uint32_t RTENR;
	__IO uint32_t FTENR;
	__IO uint32_t SWIEVR;
	__IO uint32_t INTFR;
} EXTI_TypeDef;
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

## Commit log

2026-08-10 Initial commit of hardware and firmware
    [Card Bracket v2.2 - Rev 4.FCStd, TE c-0641737-01-g-3d.stp, TE c-171826-4-y3-3d.stp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]
2026-08-12 Add hardware README (inc. bill of materials)

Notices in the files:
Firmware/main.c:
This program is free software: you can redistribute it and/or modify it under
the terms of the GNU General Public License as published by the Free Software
